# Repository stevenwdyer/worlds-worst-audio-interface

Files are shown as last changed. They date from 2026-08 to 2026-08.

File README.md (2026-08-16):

# World's Worst Audio Interface

This board consists of a TLV320AIC3100 audio codec, interfaced with a dual-core 480 MHz STM32H745IIT6 microcontroller, a 1/4" stereo jack with an op-amp buffer and inverting amplifier circuit, and a 1/8" headphone jack. It is USB-powered and uses SWD for flash and debug.

The goal of this project is to give me a custom, bare-metal platform on which I can try my hand at implementing audio effect algorithms from scratch, as well as record my own music.




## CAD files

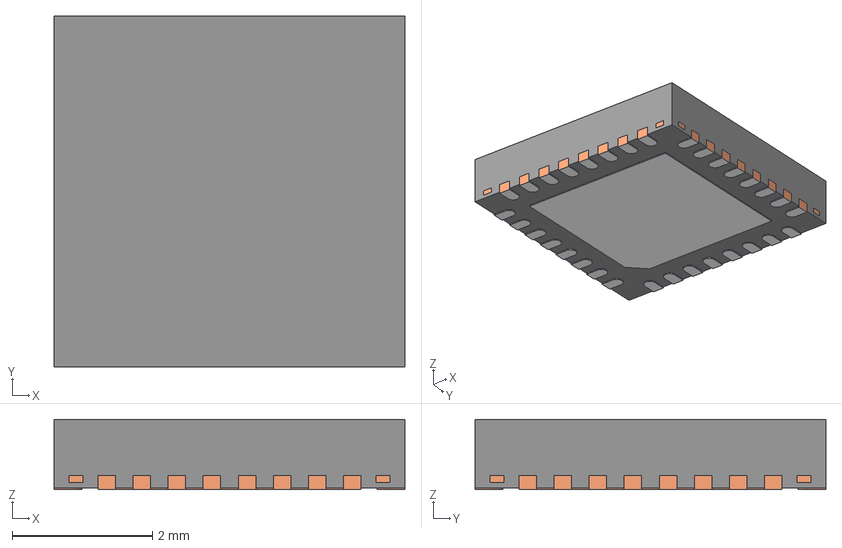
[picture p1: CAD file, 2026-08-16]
hardware/RHB0032E.stp
5.00 x 5.00 x 1.00 mm
BODY-QFN
FRAME-RHB0032E
PIN1-ID

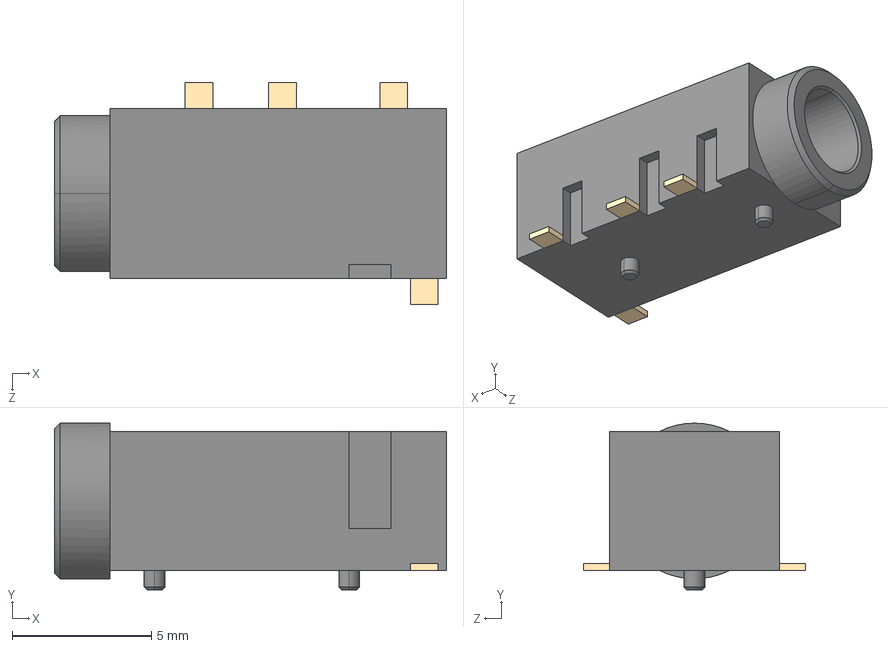
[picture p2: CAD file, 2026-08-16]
hardware/PJ-320D-A--3DModel-STEP-56544.STEP
14.1 x 6.00 x 8.00 mm

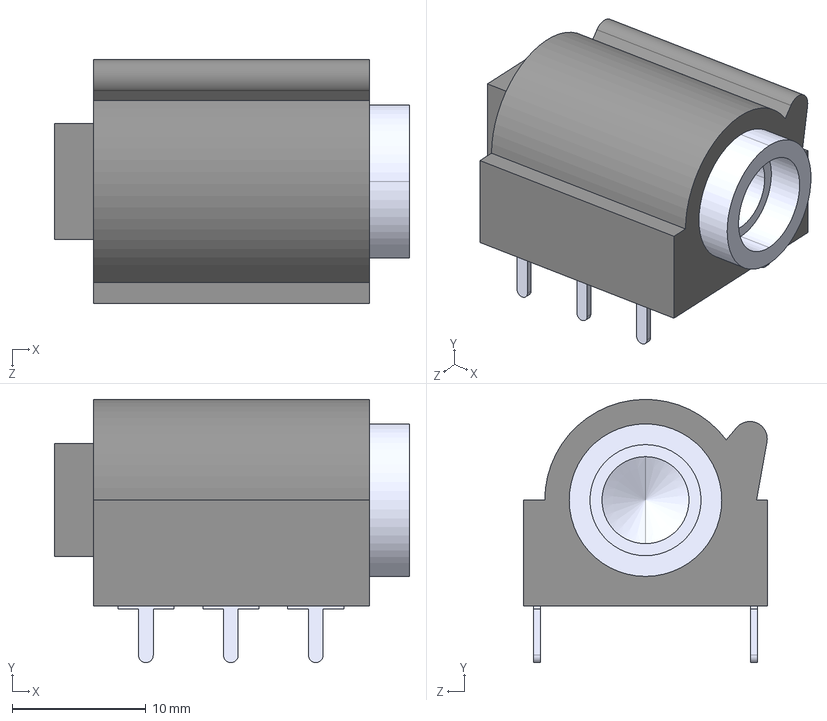
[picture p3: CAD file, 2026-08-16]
hardware/NMJ6HCD2--3DModel-STEP-56544.STEP
26.5 x 19.7 x 18.2 mm

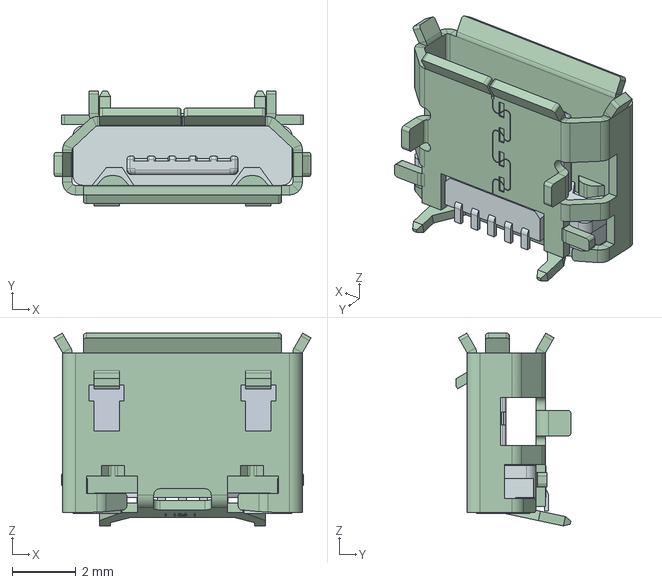
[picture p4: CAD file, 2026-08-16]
hardware/10103594.stp
8.04 x 3.60 x 6.03 mm

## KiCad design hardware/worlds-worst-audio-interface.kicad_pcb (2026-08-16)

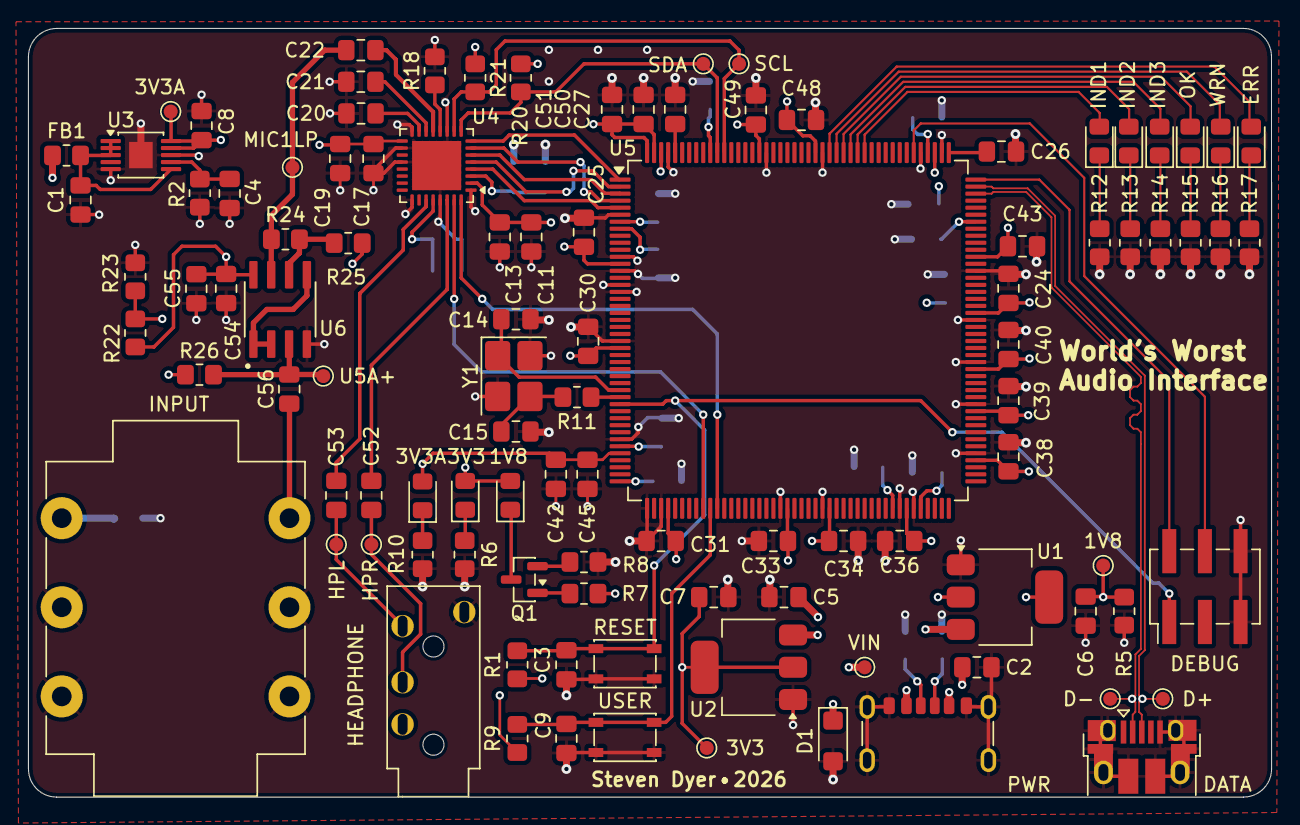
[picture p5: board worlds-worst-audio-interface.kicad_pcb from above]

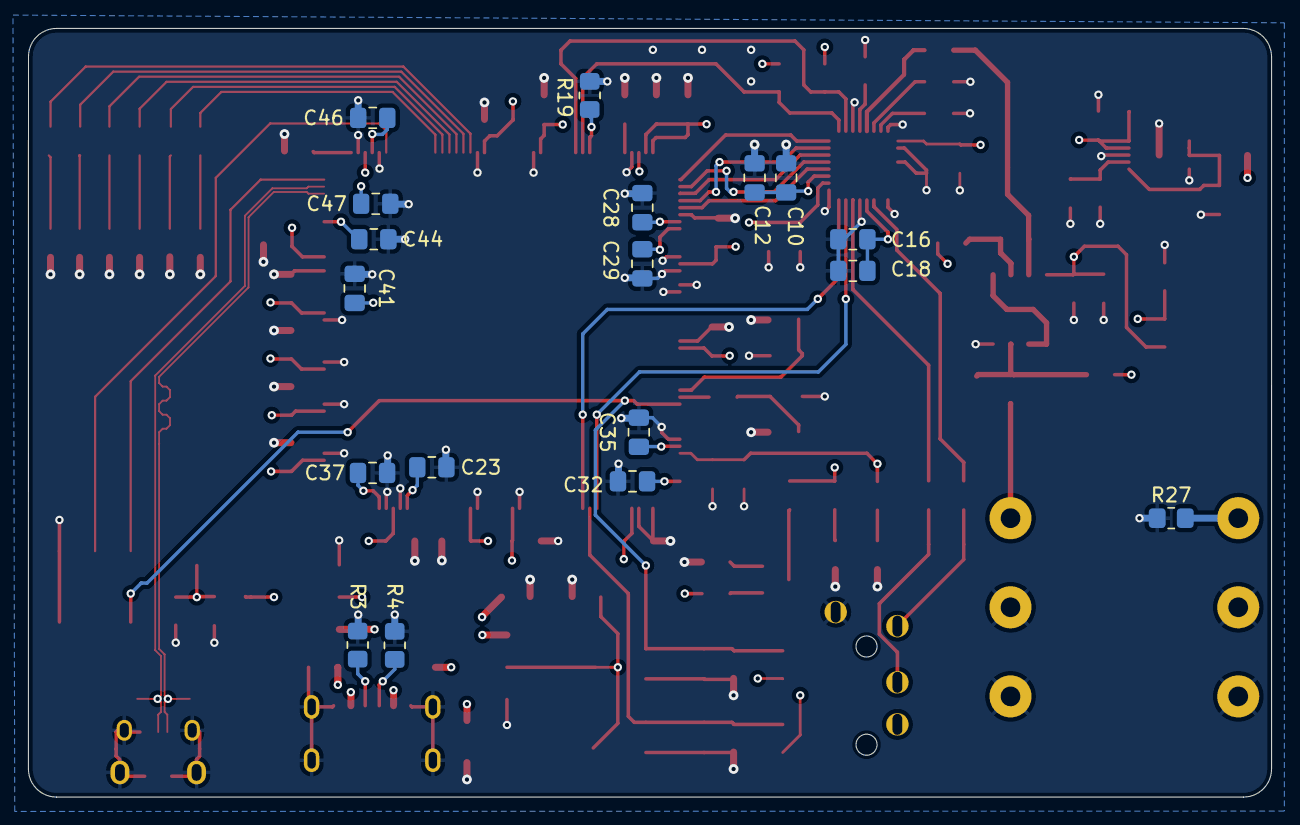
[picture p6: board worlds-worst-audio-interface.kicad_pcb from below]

Board: 4 copper layers, 88.6 x 54.8 mm, 121 parts (18 on the bottom side), 63 nets.

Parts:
1V8: +1V8; TestPoint_Pad_D1.0mm
1V8#2, 3V3A#2: LED; LED_0805_2012Metric_Pad1.15x1.40mm_HandSolder
3V3: 3V3_LED; LED_0805_2012Metric_Pad1.15x1.40mm_HandSolder
3V3#2: +3V3; TestPoint_Pad_D1.0mm
3V3A: +3.3VA; TestPoint_Pad_D1.0mm
C1, C8, C24: 4.7u; C_0805_2012Metric_Pad1.18x1.45mm_HandSolder
C2, C5, C10, C11, C16, C17, C55: 10u; C_0805_2012Metric_Pad1.18x1.45mm_HandSolder
C3, C9, C12, C13, C18, C19, C25, C28, C29, C30, C31, C33, C34, C35, C36, C37, C38, C39, C40, C41, C43, C44, C45, C46, C47, C48, C49, C50, C51, C54: 100n; C_0805_2012Metric_Pad1.18x1.45mm_HandSolder
C4: 470n; C_0805_2012Metric_Pad1.18x1.45mm_HandSolder
C6, C7: 22u; C_0805_2012Metric_Pad1.18x1.45mm_HandSolder
C14, C15: 22p; C_0805_2012Metric_Pad1.18x1.45mm_HandSolder
C20, C21, C22, C32, C42, C56: 1u; C_0805_2012Metric_Pad1.18x1.45mm_HandSolder
C23, C26, C27: 2.2u; C_0805_2012Metric_Pad1.18x1.45mm_HandSolder
C52, C53: 47u; C_0805_2012Metric_Pad1.18x1.45mm_HandSolder
D1: SMF5V0A; D_SMF
D+: USB_D+; TestPoint_Pad_D1.0mm
D-: USB_D-; TestPoint_Pad_D1.0mm
DATA: USB_B_Micro; USB_Micro-B_Amphenol_10103594-0001LF_Horizontal
DEBUG: Conn_02x03_Odd_Even; PinHeader_2x03_P2.54mm_Vertical_SMD
ERR: LED; LED_0805_2012Metric_Pad1.15x1.40mm_HandSolder
FB1: 1k@100MHz; R_0805_2012Metric_Pad1.20x1.40mm_HandSolder
HEADPHONE: PJ-320A
HPL: HPL; TestPoint_Pad_D1.0mm
HPR: HPR; TestPoint_Pad_D1.0mm
IND1, IND2, IND3: LED; LED_0805_2012Metric_Pad1.15x1.40mm_HandSolder
INPUT: NMJ6HCD2; Jack_6.35mm_Neutrik_NMJ6HCD2_Horizontal
MIC1LP: MIC1LP; TestPoint_Pad_D1.0mm
OK: LED; LED_0805_2012Metric_Pad1.15x1.40mm_HandSolder
PWR: USB_C_Receptacle_PowerOnly_6P; USB_C_Receptacle_GCT_USB4125-xx-x-0190_6P_TopMnt_Horizontal
Q1: ZXMN2A01F; SOT-23
R1, R9, R19, R22, R23, R25, R27: 10k; R_0805_2012Metric_Pad1.20x1.40mm_HandSolder
R2: 33.2k; R_0805_2012Metric_Pad1.20x1.40mm_HandSolder
R3, R4: 5k1; R_0805_2012Metric_Pad1.20x1.40mm_HandSolder
R5, R26: 1M; R_0805_2012Metric_Pad1.20x1.40mm_HandSolder
R6, R8, R10: 330; R_0805_2012Metric_Pad1.20x1.40mm_HandSolder
R7: 100; R_0805_2012Metric_Pad1.20x1.40mm_HandSolder
R11: 33; R_0805_2012Metric_Pad1.20x1.40mm_HandSolder
R12, R13, R14, R15, R16, R17: 680; R_0805_2012Metric_Pad1.20x1.40mm_HandSolder
R18: 2k2; R_0805_2012Metric_Pad1.20x1.40mm_HandSolder
R20, R21: 4k7; R_0805_2012Metric_Pad1.20x1.40mm_HandSolder
R24: 30k; R_0805_2012Metric_Pad1.20x1.40mm_HandSolder
RESET: SW_Push; SW_SPST_PTS810
SCL: I2C_SCL; TestPoint_Pad_D1.0mm
SDA: I2C_SDA; TestPoint_Pad_D1.0mm
U1: AMS1117-1.8; SOT-223-3_TabPin2
U2: AMS1117-3.3; SOT-223-3_TabPin2
U3: LT3042xMSE; MSOP-10-1EP_3x3mm_P0.5mm_EP1.68x1.88mm
U4: TLV320AIC3100; VQFN-32-1EP_5x5mm_P0.5mm_EP3.5x3.5mm
U5: STM32H745IITx; LQFP-176_24x24mm_P0.5mm
U5A+: U5A+; TestPoint_Pad_D1.0mm
U6: OPA2376xxD; OPA2376AID
USER: SW_Push; SW_SPST_PTS810
VIN: USB_VIN; TestPoint_Pad_D1.0mm
WRN: LED; LED_0805_2012Metric_Pad1.15x1.40mm_HandSolder
Y1: 12.288MHz; Crystal_SMD_3225-4Pin_3.2x2.5mm_HandSoldering

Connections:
+1V8: 1V8.1, C6.1, C10.1, C12.1, R5.1, R7.1, U1.2 (VO), U4.3 (DVDD)
+3.3VA: 3V3A.1, 3V3A#2.2 (A), C8.1, C17.1, C19.1, C42.1, C45.1, C54.1, C55.1, R22.1, U3.9 (OUTS), U3.10 (OUT), U4.17 (AVDD), U5.40 (VDDA), U6.8 (V+)
+3V3: 1V8#2.2 (A), 3V3.2 (A), 3V3#2.1, C7.1, C11.1, C13.1, C16.1, C18.1, C24.1, C25.1, C28.1, C29.1, C30.1, C31.1, C32.1, C33.1, C34.1, C35.1, C36.1, C37.1, C38.1, C39.1, C40.1, C41.1, C43.1, C44.1, C46.1, C47.1, C48.1, C49.1, C50.1, C51.1, R1.1, R9.1, R20.1, R21.1, U2.2 (VO), U4.2 (IOVDD), U4.28 (HPVDD), U5.7 (VDD), U5.8 (VBAT), U5.13 (VDD), U5.25 (VDD), U5.39 (VREF+), U5.44 (VDD), U5.48 (VDD), U5.65 (VDD), U5.71 (VDD), U5.82 (VDDLDO), U5.84 (VDD), U5.92 (VDD), U5.99 (VDD), U5.105 (VDD), U5.113 (VDD), U5.121 (VDD33_USB), U5.126 (VDD), U5.135 (VDDLDO), U5.136 (VDD), U5.152 (VDD), U5.160 (VDD), U5.174 (PDR_ON), U5.175 (VDDLDO), U5.176 (VDD)
/CODEC_GPIO: U4.32 (GPIO1), U5.55 (PB0)
/HPL: C53.1, U4.27 (HPL)
/HPR: C52.1, U4.30 (HPR)
/I2C_SCL: R21.2, SCL.1, U4.10 (SCL), U5.165 (PB6)
/I2C_SDA: R20.2, SDA.1, U4.9 (SDA), U5.166 (PB7)
/LED_ERR: ERR.2 (A), U5.150 (PD7)
/LED_IND1: IND1.2 (A), U5.145 (PD2)
/LED_IND2: IND2.2 (A), U5.146 (PD3)
/LED_IND3: IND3.2 (A), U5.147 (PD4)
/LED_OK: OK.2 (A), U5.148 (PD5)
/LED_WRN: U5.149 (PD6), WRN.2 (A)
/MIC1LP: C22.2, MIC1LP.1, R24.1, U6.7
/OSC_IN: C14.1, U5.31 (PH0), Y1.1
/OSC_OUT: R11.2, U5.32 (PH1)
/RESET: C3.1, DEBUG.1, R1.2, RESET.1, U5.33 (NRST)
/RESET_CODEC: U4.31 (~RESET), U5.53 (PC4)
/SAI1_FS_A: U4.6 (WCLK), U5.3 (PE4)
/SAI1_MCLK_A: U4.8 (MCLK), U5.1 (PE2)
/SAI1_SCK_A: U4.7 (BCLK), U5.4 (PE5)
/SAI1_SD_A: U4.4 (DOUT), U5.5 (PE6)
/SAI1_SD_B: U4.5 (DIN), U5.2 (PE3)
/SWDCLK: DEBUG.4, U5.138 (PA14)
/SWDIO: DEBUG.2, U5.132 (PA13)
/USB_D+: D+.1, DATA.3 (D+), U5.131 (PA12)
/USB_D-: D-.1, DATA.2 (D-), U5.130 (PA11)
/USB_VIN: C2.1, C5.1, D1.1 (A1), FB1.1, PWR.A9 (VBUS), PWR.B9 (VBUS), U1.3 (VI), U2.3 (VI), VIN.1
/USER_BTN: C9.1, R9.2, U5.54 (PC5), USER.1
/VBIAS: R22.2, R23.1, R25.2, R26.1
GND: C1.2, C2.2, C3.2, C4.2, C5.2, C6.2, C7.2, C8.2, C9.2, C10.2, C11.2, C12.2, C13.2, C14.2, C15.1, C16.2, C17.2, C18.2, C19.2, C20.2, C21.2, C23.2, C24.2, C25.2, C26.2, C27.2, C28.2, C29.2, C30.2, C31.2, C32.2, C33.2, C34.2, C35.2, C36.2, C37.2, C38.2, C39.2, C40.2, C41.2, C42.2, C43.2, C44.2, C45.2, C46.2, C47.2, C48.2, C49.2, C50.2, C51.2, C54.2, C55.2, D1.2 (A2), DATA.5 (GND), DATA.6 (Shield), DEBUG.5, DEBUG.6, HEADPHONE.1 (Sleeve), INPUT.R, INPUT.RN, INPUT.S, INPUT.SN, PWR.A12 (GND), PWR.B12 (GND), PWR.S1 (SHIELD), R2.2, R3.2, R4.2, R5.2, R6.1, R8.1, R10.1, R12.2, R13.2, R14.2, R15.2, R16.2, R17.2, R18.2, R19.2, R23.2, R27.1, RESET.2, U1.1 (GND), U2.1 (GND), U3.5 (ILIM), U3.8 (GND), U3.11 (GND), U4.1 (IOVSS), U4.11 (VOL/MICDET), U4.16 (AVSS), U4.18 (DVSS), U4.20 (SPKVSS), U4.25 (SPKVSS), U4.29 (HPVSS), U4.33 (EP), U5.6 (VSS), U5.12 (VSS), U5.14 (VSSSMPS), U5.16 (VDDSMPS), U5.17 (VFBSMPS), U5.24 (VSS), U5.38 (VSSA), U5.45 (VSS), U5.47 (VSS), U5.64 (VSS), U5.70 (VSS), U5.81 (VSS), U5.83 (VSS), U5.93 (VSS), U5.100 (VSS), U5.106 (VSS), U5.112 (VSS), U5.119 (VSS), U5.134 (VSS), U5.137 (VSS), U5.151 (VSS), U5.159 (VSS), U5.173 (VSS), U6.4 (V-), USER.2, Y1.2 (G), Y1.4 (G)
unnamed: C15.2, R11.1, Y1.3
unnamed: C23.1, U5.80 (VCAP)
unnamed: C26.1, U5.133 (VCAP)
unnamed: C27.1, U5.172 (VCAP)
unnamed: C56.2, INPUT.T
unnamed: 3V3.1 (K), R6.2
unnamed: 1V8#2.1 (K), Q1.3 (D)
unnamed: 3V3A#2.1 (K), R10.2
unnamed: IND1.1 (K), R12.1
unnamed: IND2.1 (K), R13.1
unnamed: IND3.1 (K), R14.1
unnamed: OK.1 (K), R15.1
unnamed: R16.1, WRN.1 (K)
unnamed: ERR.1 (K), R17.1
unnamed: PWR.A5 (CC1), R4.1
unnamed: PWR.B5 (CC2), R3.1
unnamed: INPUT.TN, R27.2
unnamed: Q1.1 (G), R7.2
unnamed: Q1.2 (S), R8.2
unnamed: C1.1, FB1.2, U3.1 (IN), U3.2 (IN), U3.3 (EN/UV), U3.6 (PGFB)
unnamed: C4.1, R2.1, U3.7 (SET)
unnamed: C20.1, U4.15 (MIC1LM)
unnamed: C22.1, U4.13 (MIC1LP)
unnamed: C21.1, U4.14 (MIC1RP)
unnamed: R18.1, U4.12 (MICBIAS)
unnamed: R19.1, U5.167 (BOOT0)
unnamed: C56.1, R26.2, U5A+.1, U6.3 (+)
unnamed: U6.1, U6.2 (-), U6.5 (+)
unnamed: R24.2, R25.1, U6.6 (-)
unnamed: C52.2, HEADPHONE.3 (Ring1), HPR.1
unnamed: C53.2, HEADPHONE.2 (Tip), HPL.1

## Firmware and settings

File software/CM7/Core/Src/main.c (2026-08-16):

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
/* Includes ------------------------------------------------------------------*/
#include "main.h"

/* USER CODE BEGIN PD */

/* DUAL_CORE_BOOT_SYNC_SEQUENCE: Define for dual core boot synchronization    */
/*                             demonstration code based on hardware semaphore */
/* This define is present in both CM7/CM4 projects                            */
/* To comment when developping/debugging on a single core                     */
#define DUAL_CORE_BOOT_SYNC_SEQUENCE

#if defined(DUAL_CORE_BOOT_SYNC_SEQUENCE)
#ifndef HSEM_ID_0
#define HSEM_ID_0 (0U) /* HW semaphore 0*/
#endif
#endif /* DUAL_CORE_BOOT_SYNC_SEQUENCE */

/* USER CODE END PD */


I2C_HandleTypeDef hi2c1;

SAI_HandleTypeDef hsai_BlockA1;
SAI_HandleTypeDef hsai_BlockB1;

void SystemClock_Config(void);
static void MPU_Config(void);
static void MX_GPIO_Init(void);
static void MX_I2C1_Init(void);
static void MX_SAI1_Init(void);
/**
  * @brief  The application entry point.
  * @retval int
  */
int main(void)
{

/* USER CODE BEGIN Boot_Mode_Sequence_0 */
#if defined(DUAL_CORE_BOOT_SYNC_SEQUENCE)
  int32_t timeout;
#endif /* DUAL_CORE_BOOT_SYNC_SEQUENCE */
/* USER CODE END Boot_Mode_Sequence_0 */

  /* MPU Configuration--------------------------------------------------------*/
  MPU_Config();

/* USER CODE BEGIN Boot_Mode_Sequence_1 */
#if defined(DUAL_CORE_BOOT_SYNC_SEQUENCE)
  /* Wait until CPU2 boots and enters in stop mode or timeout*/
  timeout = 0xFFFF;
  while((__HAL_RCC_GET_FLAG(RCC_FLAG_D2CKRDY) != RESET) && (timeout-- > 0));
  if ( timeout < 0 )
  {
  Error_Handler();
  }
#endif /* DUAL_CORE_BOOT_SYNC_SEQUENCE */
/* USER CODE END Boot_Mode_Sequence_1 */
  /* MCU Configuration--------------------------------------------------------*/

  /* Reset of all peripherals, Initializes the Flash interface and the Systick. */
  HAL_Init();

  /* Configure the system clock */
  SystemClock_Config();
/* USER CODE BEGIN Boot_Mode_Sequence_2 */
#if defined(DUAL_CORE_BOOT_SYNC_SEQUENCE)
/* When system initialization is finished, Cortex-M7 will release Cortex-M4 by means of
HSEM notification */
/*HW semaphore Clock enable*/
__HAL_RCC_HSEM_CLK_ENABLE();
/*Take HSEM */
HAL_HSEM_FastTake(HSEM_ID_0);
/*Release HSEM in order to notify the CPU2(CM4)*/
HAL_HSEM_Release(HSEM_ID_0,0);
/* wait until CPU2 wakes up from stop mode */
timeout = 0xFFFF;
while((__HAL_RCC_GET_FLAG(RCC_FLAG_D2CKRDY) == RESET) && (timeout-- > 0));
if ( timeout < 0 )
{
Error_Handler();
}
#endif /* DUAL_CORE_BOOT_SYNC_SEQUENCE */
/* USER CODE END Boot_Mode_Sequence_2 */

  /* Initialize all configured peripherals */
  MX_GPIO_Init();
  MX_I2C1_Init();
  MX_SAI1_Init();
  /* Infinite loop */
  /* USER CODE BEGIN WHILE */
  while (1)
  {
    /* USER CODE END WHILE */

    /* USER CODE BEGIN 3 */
  }
  /* USER CODE END 3 */
}

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
 /* MPU Configuration */

void MPU_Config(void)
{
  MPU_Region_InitTypeDef MPU_InitStruct = {0};

  /* Disables the MPU */
  HAL_MPU_Disable();

  /** Initializes and configures the Region and the memory to be protected
  */
  MPU_InitStruct.Enable = MPU_REGION_ENABLE;
  MPU_InitStruct.Number = MPU_REGION_NUMBER0;
  MPU_InitStruct.BaseAddress = 0x0;
  MPU_InitStruct.Size = MPU_REGION_SIZE_4GB;
  MPU_InitStruct.SubRegionDisable = 0x87;
  MPU_InitStruct.TypeExtField = MPU_TEX_LEVEL0;
  MPU_InitStruct.AccessPermission = MPU_REGION_NO_ACCESS;
  MPU_InitStruct.DisableExec = MPU_INSTRUCTION_ACCESS_DISABLE;
  MPU_InitStruct.IsShareable = MPU_ACCESS_SHAREABLE;
  MPU_InitStruct.IsCacheable = MPU_ACCESS_NOT_CACHEABLE;
  MPU_InitStruct.IsBufferable = MPU_ACCESS_NOT_BUFFERABLE;

  HAL_MPU_ConfigRegion(&MPU_InitStruct);
  /* Enables the MPU */
  HAL_MPU_Enable(MPU_PRIVILEGED_DEFAULT);

}

/**
  * @brief  This function is executed in case of error occurrence.
  * @retval None
  */
void Error_Handler(void)
{
  /* USER CODE BEGIN Error_Handler_Debug */
  /* User can add his own implementation to report the HAL error return state */
  __disable_irq();
  while (1)
  {
  }
  /* USER CODE END Error_Handler_Debug */
}
#ifdef USE_FULL_ASSERT
/**
  * @brief  Reports the name of the source file and the source line number
  *         where the assert_param error has occurred.
  * @param  file: pointer to the source file name
  * @param  line: assert_param error line source number
  * @retval None
  */
void assert_failed(uint8_t *file, uint32_t line)
{
  /* USER CODE BEGIN 6 */
  /* User can add his own implementation to report the file name and line number,
     ex: printf("Wrong parameters value: file %s on line %d\r\n", file, line) */
  /* USER CODE END 6 */
}
#endif /* USE_FULL_ASSERT */

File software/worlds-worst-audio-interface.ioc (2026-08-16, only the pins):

Mcu.UserName=STM32H745IITx
PA11.Signal=USB_OTG_FS_DM
PA12.Signal=USB_OTG_FS_DP
PB6.Signal=I2C1_SCL
PB7.Signal=I2C1_SDA
PD2.GPIO_Label=LED_IND1
PD2.Signal=GPIO_Output
PD3.GPIO_Label=LED_IND2
PD3.Signal=GPIO_Output
PD4.GPIO_Label=LED_IND3
PD4.Signal=GPIO_Output
PD5.GPIO_Label=LED_OK
PD5.Signal=GPIO_Output
PD6.GPIO_Label=LED_WRN
PD6.Signal=GPIO_Output
PD7.GPIO_Label=LED_ERR
PD7.Signal=GPIO_Output
PE2.Signal=SAI1_MCLK_A
PE3.Signal=SAI1_SD_B
PE4.Signal=SAI1_FS_A
PE5.Signal=SAI1_SCK_A
PE6.Signal=SAI1_SD_A

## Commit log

2026-08-16 Add hardware revision 1
    [10103594.stp, NMJ6HCD2--3DModel-STEP-56544.STEP, PJ-320D-A--3DModel-STEP-56544.STEP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]
2026-08-16 Add STM32CubeIDE project with boilerplate HAL code

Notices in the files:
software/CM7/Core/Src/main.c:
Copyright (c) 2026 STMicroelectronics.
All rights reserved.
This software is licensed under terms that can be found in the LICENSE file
